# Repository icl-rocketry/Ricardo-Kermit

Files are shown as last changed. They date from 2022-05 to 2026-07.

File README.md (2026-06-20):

# Kermit
RAE board designed for data acquisition. All versions currently include power regulation for different types of analog sensors, as well as ADC and TC inputs.

# Supported Versions

## v3
v3 Kermit (nicknamed Kermit mini) includes:
  - [Ricardo Template](https://github.com/icl-rocketry/Ricardo-BoardTemplate) components.
  - 5V and 12V power outputs from an LDO.
  - 4 ADC channels with a theoretical maximum of 64kSPS from 1x ADS131M04 chip. All 4 channels can be configured for differential and single-ended inputs, 4-20mA input, voltage sensor input.
  - 2 Thermocouple chips (MAX31856) supporting every type of thermocouple.
  - SD Card for in-flight, and high rate, data acquisition.
  
## v2
v2 Kermit includes:
  - [Ricardo Template](https://github.com/icl-rocketry/Ricardo-BoardTemplate) components.
  - 5V and 10V power outputs from an LDO.
  - 12 ADC channels with a theoretical maximum of 32kSPS from 2x ADS131M06 chips. All 12 channels can be configured for differential and single-ended inputs, and 3.3V supply voltage sensors. 10 of the channels can be configured for 5v voltage-based sensors, and 2 of the channels can be configured for 4-20mA sensors (10V supply).
  - 4 Thermocouple chips (MAX31856) supporting every type of thermocouple.
  - SD Card for in-flight, and high rate, data acquisition.

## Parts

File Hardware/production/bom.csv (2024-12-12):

Designator | Footprint | Quantity | Value | LCSC Part #
12VLED1 | 0402 | 1 | RED_LED
3V3LED1 | 0402 | 1 | BLUE_LED
BOOTJUMPER1, ENJUMPER1 | PinHeader_1x02_P2.54mm_Vertical | 2 | Conn_01x02_Male
C1, C16, C20, C24, C26 | 0402 | 5 | 10uF
C10, C11, C27, C3, C49, C5, C54, C56, C57, C59, C6, C61, C62, C8 | 0402 | 14 | 0.1uF
C12 | 0603 | 1 | 2.2uF
C13, C14 | 0402 | 2 | 11pF
C15, C31, C33, C44, C45 | 0402 | 5 | 100nF
C17 | 0402 | 1 | 47nF
C18 | 0402 | 1 | 180pF
C19 | 0402 | 1 | 3.9nF
C2, C22, C4, C50, C51, C7 | 0402 | 6 | 1uF
C21, C38 | 0603 | 2 | 10uF
C23 | 0603 | 1 | 22uF
C25 | 0402 | 1 | 4.7uF
C28, C37 | 0402 | 2 | 1uF | CL05X105KA5NQNC
C29, C30, C41, C43 | 0805 | 4 | 22uF
C32, C42 | 0402 | 2 | 2.2uF | GRM155R61E225ME15D
C34 | 1206 | 1 | 47uF
C35 | 0402 | 1 | 10uF | CL05A106MP8NUB8
C36, C47 | 0402 | 2 | 100nF | C1005X5R1E104KT000E
C39 | 0402 | 1 | 120pF
C40 | 0402 | 1 | 2.2nF
C46 | 0603 | 1 | 10uF | TMK107BBJ106MA-T
C48 | 1206 | 1 | 22uF
C52 | 0402 | 1 | 220nF
C53, C55, C58, C60 | 0402 | 4 | 0.01uF
C63, C64, C65, C66, C9 | 0402 | 5 | 10nF
CANRXLED1 | 0402 | 1 | CANRXLED
CANTXLED1 | 0402 | 1 | CANTXLED
D1 | SOT-23 | 1 | SM712_SOT23
D2 | SOT-143 | 1 | SP0503BAHT
D3 | SOT-23 | 1 | MMBZ6V2ALT1G | MMBZ6V2ALT1G
D6 | RCLAMP3346PQTNT | 1 | RCLAMP3346PQTNT
H1, H2, H3, H4 | MountingHole_3.2mm_M3_DIN965_Pad | 4 | MountingHole_Pad
IC1, IC4 | IC_TPS61089RNRR | 2 | TPS61089RNRR | TPS61089RNRR
IC2, IC3 | SOT95P282X145-5N | 2 | AP2205-W5-7 | AP2205-W5-7
IC5 | QFN40P300X300X80-21N-D | 1 | ADS131M04IRUKR
J1 | Molex_Mini-Fit_Jr_5566-06A_2x03_P4.20mm_Vertical | 1 | RBUS
J2 | USB_C_Receptacle_Palconn_UTC16-G | 1 | USB_C_Receptacle_USB2.0
J4, J5, J6, J7 | Molex_Nano-Fit_105313-xx04_1x04_P2.50mm_Horizontal | 4 | 1053131104
J8 | PinSocket_2x05_P2.54mm_Vertical | 1 | GPIO Breakout
J9 | JAE_ST1W008S4TR2000 | 1 | ST1W008S4TR2000
JP1 | SolderJumper-2_P1.3mm_Open_RoundedPad1.0x1.5mm | 1 | TermJP
JP10, JP11, JP12, JP13, JP14, JP17, JP20, JP22, JP3, JP4, JP5, JP6 | SolderJumper-3_P1.3mm_Open_RoundedPad1.0x1.5mm_NumberLabels | 12 | SolderJumper_3_Open
JP15, JP16, JP18, JP19, JP2, JP21, JP7, JP8, JP9 | SmallerSolderJP | 9 | SolderJumper_2_Open
L1 | 0402 | 1 | 2.0nH
L2 | 0402 | 1 | 20nH
L3 | 0805 | 1 | 1uH
L4, L5 | IND_SRP6540-390M | 2 | SRR6038-5R0Y
Q1 | SOT-23 | 1 | PMOS | DMP3099L
R1, R14, R17, R20, R29, R3, R32, R38, R46, R61 | 0402 | 10 | 10K
R10, R9 | 0603 | 2 | 60
R11, R12, R13 | 0402 | 3 | 5.1k
R15, R36, R43, R49 | 0402 | 4 | 14k
R16 | 0402 | 1 | 56k
R18 | 0402 | 1 | 360k
R19, R27 | 0402 | 2 | 100k
R2, R4 | 0402 | 2 | 470
R21 | 0402 | 1 | 560k
R22, R28 | 0402 | 2 | 49.9k
R23 | 0402 | 1 | 150k
R24 | 0402 | 1 | 301k
R25 | 0402 | 1 | 18.7k
R26 | 0402 | 1 | 976k
R30 | 0402 | 1 | 475k
R31 | 0402 | 1 | 287k
R33, R40, R45, R48, R55, R56, R57, R58, R60, R62, R64 | 0402 | 11 | 1k
R34, R42, R47 | 0402 | 3 | 75k
R35 | 0402 | 1 | 75k | RT0402BRD0775KL
R37 | 0402 | 1 | 10k | ERA2ARB103X
R39 | 0402 | 1 | 14k | 0402WGF1402TCE
R41, R44, R59, R63 | 0402 | 4 | 49.9 | RT0402BRD0749R9L
R5 | 0402 | 1 | 7.87k
R50, R51, R52, R53 | 0402 | 4 | 100
R54 | 0402 | 1 | 54.9R
R6 | 0402 | 1 | 499R | AC0402FR-07499RL
R65 | 0402 | 1 | 432k
R7 | 0402 | 1 | 3k
R8 | 0603 | 1 | 0
TC1, TC2 | Molex_Nano-Fit_105313-xx02_1x02_P2.50mm_Horizontal | 2 | Thermocouple
TP1, TP2, TP3, TP4 | TestPoint_Pad_D1.0mm | 4 | TestPoint
TP5, TP6 | TestPoint_Pad_D1.5mm | 2 | TestPoint
TXLED1 | 0402 | 1 | GREEN_LED
U1 | QFN40P700X700X90-57N | 1 | ESP32-S3
U2 | SOIC-8_3.9x4.9mm_P1.27mm | 1 | SN65HVD230
U3 | SOTFL50P160X60-8N | 1 | LM66200DRLR
U4 | CONV_MAX77827AEFD+T | 1 | MAX77827AEFD+T
U5 | SOIC127P599X175-9N | 1 | SC4215
U6, U7 | TSSOP-14_4.4x5mm_P0.65mm | 2 | MAX31856
USBLED1 | 0402 | 1 | WHITE_LED
Y1 | Crystal_SMD_2016-4Pin_2.0x1.6mm | 1 | R940000171

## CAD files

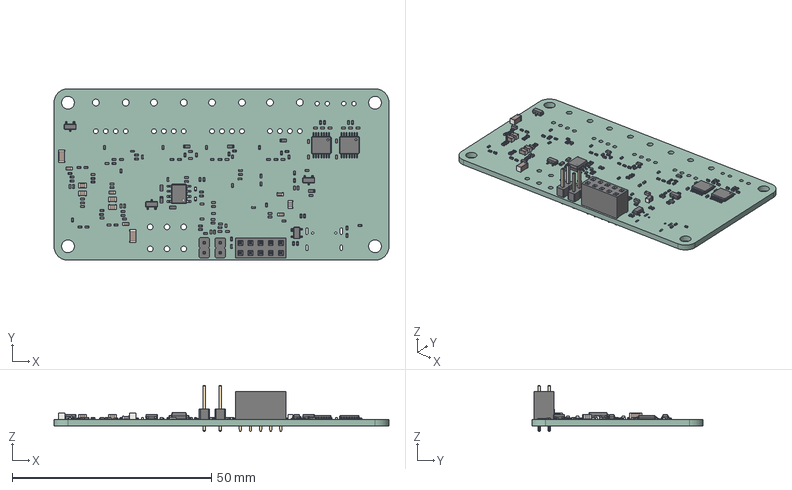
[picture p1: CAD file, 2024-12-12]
Hardware/Ricardo-Kermit-Mini.step
84.0 x 43.0 x 11.6 mm
R_0402_1005Metric x 66
C_0402_1005Metric x 55
R_0603_1608Metric x 7
C_0603_1608Metric x 5
PinSocket_2x05_P254mm_Vertical
TSSOP_14_44x5mm_P065mm x 2
L_0402_1005Metric x 2
C_1206_3216Metric x 2
PinHeader_1x02_P254mm_Vertical x 2
C_0805_2012Metric x 4
SOT_23 x 3
SOIC_8_39x49mm_P127mm
LED_0402_1005Metric x 2
SOT_143
L_0805_2012Metric
Ricardo-Kermit-Mini_PCB

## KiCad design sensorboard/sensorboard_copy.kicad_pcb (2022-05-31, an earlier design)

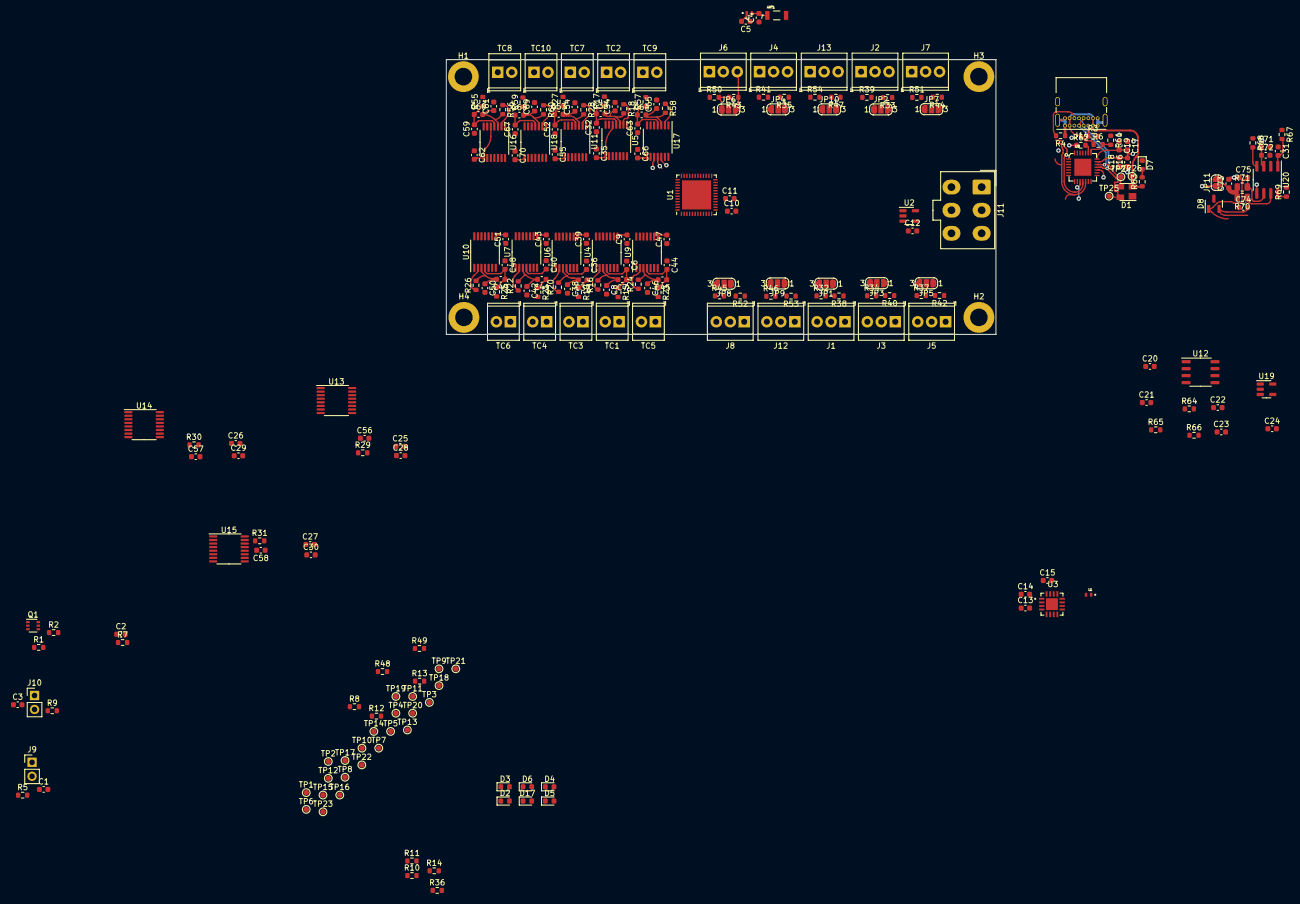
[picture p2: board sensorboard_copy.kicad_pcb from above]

Board: 4 copper layers, 100.0 x 50.0 mm, 244 parts (0 on the bottom side), 132 nets.

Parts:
ANT1: AMCA31-2R450G-S1F-T3; ANT_AMCA31-2R450G-S1F-T3
C1, C2, C3: 1nF; C_0603_1608Metric
C4: 1.2pF; C_0603_1608Metric
C5: 1.5pF; C_0603_1608Metric
C6, C8, C32, C34, C36, C38, C40, C42, C44, C46, C48, C50, C52, C54, C59, C61, C63, C65, C67, C69: 0.01uF; C_0603_1608Metric
C7, C9, C18, C19, C22, C33, C35, C37, C39, C41, C43, C45, C47, C49, C51, C53, C55, C56, C57, C58, C60, C62, C64, C66, C68, C70, C73: 0.1uF; C_0603_1608Metric
C10, C13, C20, C23, C25, C26, C27, C72: 10uF; C_0603_1608Metric
C11, C28, C29, C30, C71: 100nF; C_0603_1608Metric
C12, C16, C24: 4.7uF; C_0603_1608Metric
C14: 2.2uF; C_0603_1608Metric
C15: 100uF; C_0603_1608Metric
C17: 1.0uF; C_0603_1608Metric
C21: 1uF; C_0603_1608Metric
C31: 160pF; C_0603_1608Metric
C74: 220pF; C_0603_1608Metric
C75: 220 pF; C_0603_1608Metric
D1: SP0503BAHT; SOT-143
D2: RX_LED; LED_0603_1608Metric
D3: TX_LED; LED_0603_1608Metric
D4, D5: LED; LED_0603_1608Metric
D6: PWR_LED; LED_0603_1608Metric
D7, D17: USB_LED; LED_0603_1608Metric
D8: SM712_SOT23; SOT-23
H1, H2, H3, H4: MountingHole_Pad; MountingHole_3.2mm_M3_DIN965_Pad
J1, J2, J3, J4, J5, J6, J7, J8, J12, J13: Conn_01x03; TerminalBlock_TE_282834-3_1x03_P2.54mm_Horizontal
J9, J10: Conn_01x02_Male; PinHeader_1x02_P2.54mm_Vertical
J11: Conn_01x05_Male; Molex_Mini-Fit_Jr_5566-06A_2x03_P4.20mm_Vertical
J14: USB_C_Receptacle_USB2.0; USB_C_Receptacle_GCT_USB4085
JP1, JP2, JP3, JP4, JP5, JP6, JP7, JP8, JP9, JP10: SolderJumper_3_Open; SolderJumper-3_P1.3mm_Open_RoundedPad1.0x1.5mm_NumberLabels
JP11: SolderJumper_2_Open; SolderJumper-2_P1.3mm_Open_RoundedPad1.0x1.5mm
L1: 6.8uH; INDC1006X60N
L2: LQG15WZ1N8B02D; INDC1006X60N
Q1: MMDT2222A; SOT-363_SC-70-6
R1, R2, R7, R8: 10K; R_0603_1608Metric
R3, R4: 5.1k; R_0603_1608Metric
R5, R9, R10, R11, R12, R13, R14, R36, R63: 470; R_0603_1608Metric
R6: 24k; R_0603_1608Metric
R15, R16, R17, R18, R19, R20, R21, R22, R23, R24, R25, R26, R27, R28, R55, R56, R57, R58, R59, R60: 100; R_0603_1608Metric
R29, R30, R31, R48, R49: 1k; R_0603_1608Metric
R32, R33, R34, R35, R37, R43, R44, R45, R46, R47: 22k; R_0603_1608Metric
R38, R39, R40, R41, R42, R50, R51, R52, R53, R54: 43k; R_0603_1608Metric
R61, R66: 47k; R_0603_1608Metric
R62: 4.7k; R_0603_1608Metric
R64: 100k; R_0603_1608Metric
R65: 147k; R_0603_1608Metric
R67, R68: 90; R_0603_1608Metric
R69: 10k; R_0603_1608Metric
R70, R71: 60; R_0805_2012Metric
TC1, TC2, TC3, TC4, TC5, TC6, TC7, TC8, TC9, TC10: Thermocouple; TerminalBlock_TE_282834-2_1x02_P2.54mm_Horizontal
TP1, TP2, TP3, TP4, TP5, TP6, TP7, TP8, TP9, TP10, TP11, TP12, TP13, TP14, TP15, TP16, TP17, TP18, TP19, TP20, TP21, TP22, TP23, TP24, TP25, TP26: TestPoint; TestPoint_Pad_D1.0mm
U1: ESP32-PICO-D4; QFN-48-1EP_7x7mm_P0.5mm_EP5.3x5.3mm
U2, U19: LTC4411; SOT-23-5
U3: TPS61092RSAR; QFN65P400X400X100-17N
U4, U5, U6, U7, U9, U10, U11, U16, U17, U18: MAX31856; TSSOP-14_4.4x5mm_P0.65mm
U8: CP2102-GMR-QFN28; QFN28G_0.5-5X5MM
U12: RT9025-25GSP; SOP-8_3.9x4.9mm_P1.27mm
U13, U14, U15: ADS1219; TSSOP-16_4.4x5mm_P0.65mm
U20: SN65HVD230; SOIC-8_3.9x4.9mm_P1.27mm

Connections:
+3V3: C9.2, C10.1, C11.1, C12.1, C16.2, C17.2, C18.2, C19.2, C24.1, C25.1, C26.1, C27.1, C28.1, C29.1, C30.1, C35.2, C39.2, C43.2, C47.2, C51.2, C55.2, C56.2, C57.2, C58.2, C62.2, C66.2, C70.2, C71.1, C72.1, L1.1, R7.1, R8.1, R10.1, R11.1, R13.1, R14.2, R29.2, R30.2, R31.2, R48.2, R49.1, R62.1, U1.1 (VDDA), U1.3 (VDDA3P3), U1.4 (VDDA3P3), U1.19 (VDD3P3_RTC), U1.37 (VDD3P3_CPU), U1.43 (VDDA), U1.46 (VDDA), U2.5 (OUT), U3.8 (VBAT), U3.9 (LBI), U3.10 (SYNC), U3.11 (EN), U4.5 (AVDD), U4.8 (DVDD), U5.5 (AVDD), U5.8 (DVDD), U6.5 (AVDD), U6.8 (DVDD), U7.5 (AVDD), U7.8 (DVDD), U8.6 (VDD), U8.7 (REGIN), U9.5 (AVDD), U9.8 (DVDD), U10.5 (AVDD), U10.8 (DVDD), U11.5 (AVDD), U11.8 (DVDD), U13.3 (~RESET), U13.9 (REFP), U13.12 (AVDD), U13.13 (DVDD), U14.2 (A1), U14.3 (~RESET), U14.9 (REFP), U14.12 (AVDD), U14.13 (DVDD), U15.1 (A0), U15.2 (A1), U15.3 (~RESET), U15.9 (REFP), U15.12 (AVDD), U15.13 (DVDD), U16.5 (AVDD), U16.8 (DVDD), U17.5 (AVDD), U17.8 (DVDD), U18.5 (AVDD), U18.8 (DVDD), U19.5 (OUT), U20.3 (VCC)
+5V: C14.1, J1.2, J2.2, J3.2, J4.2, J5.2, J6.2, J7.2, J8.2, J12.2, J13.2, U3.1 (VOUT), U3.15 (VOUT), U3.16 (VOUT)
/BOOT: Q1.3 (C2), R8.2, R9.1, TP8.1, U1.23 (IO0)
/C55: TP11.1, U1.20 (IO13)
/CAN/Vref: JP11.1 (A), U20.5 (Vref)
/CAN_HIGH: C74.2, D8.2 (A2), J11.5, R70.1, U20.7 (CANH)
/CAN_LOW: C75.2, D8.1 (A1), J11.6, R71.2, U20.6 (CANL)
/CAN_RX: R68.1, TP23.1, U1.13 (IO33)
/CAN_TX: R67.1, TP22.1, U1.12 (IO32)
/CS0: TP21.1, U1.16 (IO27), U4.9 (~CS)
/CS1: TP20.1, U1.15 (IO26), U5.9 (~CS)
/CS2: TP19.1, U1.14 (IO25), U9.9 (~CS)
/CS3: TP13.1, U1.21 (IO15), U6.9 (~CS)
/CS4: TP12.1, U1.17 (IO14), U7.9 (~CS)
/CS6: TP10.1, U1.18 (IO12), U11.9 (~CS)
/CS7: TP9.1, U1.29 (SD3/IO10), U16.9 (~CS)
/CS8: TP2.1, U1.28 (SD2/IO9), U17.9 (~CS)
/CS9: TP1.1, U1.34 (IO5), U18.9 (~CS)
/DTR: Q1.4 (E2), R1.2, TP3.1, U8.28 (DTR)
/EN: C2.1, Q1.6 (C1), R5.1, R7.2, TP7.1, U1.9 (EN)
/LED: R12.1, U1.22 (IO2)
/LNA_IN: C5.2, L2.2, U1.2 (LNA_IN)
/MISO: TP15.1, U1.38 (IO19), U4.11 (SDO), U5.11 (SDO), U6.11 (SDO), U7.11 (SDO), U9.11 (SDO), U10.11 (SDO), U11.11 (SDO), U16.11 (SDO), U17.11 (SDO), U18.11 (SDO)
/MOSI: TP18.1, U1.36 (IO23), U4.12 (SDI), U5.12 (SDI), U6.12 (SDI), U7.12 (SDI), U9.12 (SDI), U10.12 (SDI), U11.12 (SDI), U16.12 (SDI), U17.12 (SDI), U18.12 (SDI)
/RTS: Q1.1 (E1), R2.2, TP6.1, U8.24 (RTS)
/RXD: D2.1 (K), TP5.1, U1.41 (U0TXD/IO1), U8.25 (RXD)
/SCL: R48.1, TP17.1, U1.39 (IO22), U13.16 (SCL), U14.16 (SCL), U15.16 (SCL)
/SCLK: TP14.1, U1.35 (IO18), U4.10 (SCK), U5.10 (SCK), U6.10 (SCK), U7.10 (SCK), U9.10 (SCK), U10.10 (SCK), U11.10 (SCK), U16.10 (SCK), U17.10 (SCK), U18.10 (SCK)
/SDA: R49.2, TP16.1, U1.42 (IO21), U13.15 (SDA), U14.15 (SDA), U15.15 (SDA)
/TXD: D3.1 (K), TP4.1, U1.40 (U0RXD/IO3), U8.26 (TXD)
/analogueI2C/AIN0: JP1.2 (C), U13.11 (AIN0)
/analogueI2C/AIN1: JP6.2 (C), U13.10 (AIN1)
/analogueI2C/AIN2: JP2.2 (C), U13.7 (AIN2)
/analogueI2C/AIN3: JP7.2 (C), U13.6 (AIN3)
/analogueI2C/AIN4: JP3.2 (C), U14.11 (AIN0)
/analogueI2C/AIN5: JP8.2 (C), U14.10 (AIN1)
/analogueI2C/AIN6: JP4.2 (C), U14.6 (AIN3)
/analogueI2C/AIN7: JP9.2 (C), U14.7 (AIN2)
/analogueI2C/AIN8: JP5.2 (C), U15.11 (AIN0)
/analogueI2C/AIN9: JP10.2 (C), U15.10 (AIN1)
/usb/Data+: D1.4 (K), J14.A6 (D+), J14.B6 (D+), TP25.1, U8.4 (D+)
/usb/Data-: D1.3 (K), J14.A7 (D-), J14.B7 (D-), TP24.1, U8.5 (D-)
GND: C1.2, C2.2, C3.2, C4.1, C5.1, C6.1, C8.2, C9.1, C10.2, C11.2, C12.2, C13.2, C14.2, C15.2, C16.1, C17.1, C18.1, C19.1, C20.1, C21.1, C23.1, C24.2, C25.2, C26.2, C27.2, C28.2, C29.2, C30.2, C31.1, C32.1, C34.2, C35.1, C36.1, C38.2, C39.1, C40.1, C42.2, C43.1, C44.1, C46.2, C47.1, C48.1, C50.2, C51.1, C52.1, C54.2, C55.1, C56.1, C57.1, C58.1, C59.1, C61.2, C62.1, C63.1, C65.2, C66.1, C67.1, C69.2, C70.1, C71.2, C72.2, C73.2, C74.1, C75.1, D1.1 (A), D4.1 (K), D5.1 (K), D6.1 (K), D7.1 (K), D8.3 (common), D17.1 (K), H1.1, H2.1, H3.1, H4.1, J1.1, J2.1, J3.1, J4.1, J5.1, J6.1, J7.1, J8.1, J9.2, J10.2, J11.1, J11.2, J12.1, J13.1, J14.A1 (GND), J14.A12 (GND), J14.B1 (GND), J14.B12 (GND), J14.S1 (SHIELD), R3.2, R4.1, R38.1, R39.1, R40.1, R41.1, R42.1, R50.1, R51.1, R52.1, R53.1, R54.1, R61.1, R64.2, R66.2, R69.2, U1.49 (GND), U2.2 (GND), U2.3 (CTL), U3.5 (PGND), U3.6 (PGND), U3.7 (PGND), U3.13 (GND), U3.17 (PGND), U4.1 (AGND), U4.14 (DGND), U5.1 (AGND), U5.14 (DGND), U6.1 (AGND), U6.14 (DGND), U7.1 (AGND), U7.14 (DGND), U8.3 (GND), U9.1 (AGND), U9.14 (DGND), U10.1 (AGND), U10.14 (DGND), U11.1 (AGND), U11.14 (DGND), U12.8 (GND), U13.1 (A0), U13.2 (A1), U13.4 (DGND), U13.5 (AGND), U13.8 (REFN), U14.1 (A0), U14.4 (DGND), U14.5 (AGND), U14.8 (REFN), U15.4 (DGND), U15.5 (AGND), U15.8 (REFN), U16.1 (AGND), U16.14 (DGND), U17.1 (AGND), U17.14 (DGND), U18.1 (AGND), U18.14 (DGND), U19.2 (GND), U19.3 (CTL), U20.2 (GND)
unnamed: ANT1.1, C4.2, L2.1
unnamed: C1.1, J9.1, R5.2
unnamed: C3.1, J10.1, R9.2
unnamed: C6.2, C7.1, R15.1, U4.4 (T+)
unnamed: C7.2, C8.1, R16.2, U4.3 (T-)
unnamed: C22.1, R65.2, R66.1, U12.7 (ADJ)
unnamed: C22.2, C23.2, R65.1, U12.6 (VOUT), U19.1 (IN)
unnamed: C31.2, R67.2, U20.1 (D)
unnamed: C32.2, C33.1, R17.1, U5.4 (T+)
unnamed: C33.2, C34.1, R18.2, U5.3 (T-)
unnamed: C36.2, C37.1, R19.1, U6.4 (T+)
unnamed: C37.2, C38.1, R20.2, U6.3 (T-)
unnamed: C40.2, C41.1, R21.1, U7.4 (T+)
unnamed: C41.2, C42.1, R22.2, U7.3 (T-)
unnamed: C44.2, C45.1, R23.1, U9.4 (T+)
unnamed: C45.2, C46.1, R24.2, U9.3 (T-)
unnamed: C48.2, C49.1, R25.1, U10.4 (T+)
unnamed: C49.2, C50.1, R26.2, U10.3 (T-)
unnamed: C52.2, C53.1, R27.1, U11.4 (T+)
unnamed: C53.2, C54.1, R28.2, U11.3 (T-)
unnamed: C59.2, C60.1, R55.1, U16.4 (T+)
unnamed: C60.2, C61.1, R56.2, U16.3 (T-)
unnamed: C63.2, C64.1, R57.1, U17.4 (T+)
unnamed: C64.2, C65.1, R58.2, U17.3 (T-)
unnamed: C67.2, C68.1, R59.1, U18.4 (T+)
unnamed: C68.2, C69.1, R60.2, U18.3 (T-)
unnamed: C73.1, JP11.2 (B), R70.2, R71.1
unnamed: D2.2 (A), R10.2
unnamed: D3.2 (A), R11.2
unnamed: D4.2 (A), R12.2
unnamed: D5.2 (A), R13.2
unnamed: D6.2 (A), R14.1
unnamed: D7.2 (A), R63.2
unnamed: D17.2 (A), R36.2
unnamed: J1.3, JP1.3 (B), R32.1
unnamed: J2.3, JP2.3 (B), R33.1
unnamed: J3.3, JP3.3 (B), R34.1
unnamed: J4.3, JP4.3 (B), R35.1
unnamed: J5.3, JP5.3 (B), R37.1
unnamed: J6.3, JP6.3 (B), R43.1
unnamed: J7.3, JP7.3 (B), R44.1
unnamed: J8.3, JP8.3 (B), R45.1
unnamed: J11.3, U2.1 (IN)
unnamed: J12.3, JP9.3 (B), R46.1
unnamed: J13.3, JP10.3 (B), R47.1
unnamed: J14.A5 (CC1), R3.1
unnamed: J14.B5 (CC2), R4.2
unnamed: JP1.1 (A), R32.2, R38.2
unnamed: JP2.1 (A), R33.2, R39.2
unnamed: JP3.1 (A), R34.2, R40.2
unnamed: JP4.1 (A), R35.2, R41.2
unnamed: JP5.1 (A), R37.2, R42.2
unnamed: JP6.1 (A), R43.2, R50.2
unnamed: JP7.1 (A), R44.2, R51.2
unnamed: JP8.1 (A), R45.2, R52.2
unnamed: JP9.1 (A), R46.2, R53.2
unnamed: JP10.1 (A), R47.2, R54.2
unnamed: L1.2, U3.3 (SW), U3.4 (SW)
unnamed: Q1.2 (B1), R1.1
unnamed: Q1.5 (B2), R2.1
unnamed: R6.2, R61.2, U8.8 (VBUS)
unnamed: R15.2, TC1.1 (+)
unnamed: R16.1, TC1.2 (-), U4.2 (BIAS)
unnamed: R17.2, TC2.1 (+)
unnamed: R18.1, TC2.2 (-), U5.2 (BIAS)
unnamed: R19.2, TC3.1 (+)
unnamed: R20.1, TC3.2 (-), U6.2 (BIAS)
unnamed: R21.2, TC4.1 (+)
unnamed: R22.1, TC4.2 (-), U7.2 (BIAS)
unnamed: R23.2, TC5.1 (+)
unnamed: R24.1, TC5.2 (-), U9.2 (BIAS)
unnamed: R25.2, TC6.1 (+)
unnamed: R26.1, TC6.2 (-), U10.2 (BIAS)
unnamed: R27.2, TC7.1 (+)
unnamed: R28.1, TC7.2 (-), U11.2 (BIAS)
unnamed: R29.1, U13.14 (~DRDY)
unnamed: R30.1, U14.14 (~DRDY)
unnamed: R31.1, U15.14 (~DRDY)
unnamed: R55.2, TC8.1 (+)
unnamed: R56.1, TC8.2 (-), U16.2 (BIAS)
unnamed: R57.2, TC9.1 (+)
unnamed: R58.1, TC9.2 (-), U17.2 (BIAS)
unnamed: R59.2, TC10.1 (+)
unnamed: R60.1, TC10.2 (-), U18.2 (BIAS)
unnamed: R62.2, U8.9 (~RST)
unnamed: R64.1, U12.1 (PGOOD)
unnamed: R68.2, U20.4 (R)
unnamed: R69.1, U20.8 (Rs)
VBUS: C20.2, C21.2, D1.2 (K), J14.A4 (VBUS), J14.A9 (VBUS), J14.B4 (VBUS), J14.B9 (VBUS), R6.1, R63.1, TP26.1, U12.2 (EN), U12.3 (VIN), U12.4 (VDD)

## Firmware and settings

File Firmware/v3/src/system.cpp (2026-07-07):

#include "system.h"

#include <memory>

#include <libriccore/riccoresystem.h>

#include <HardwareSerial.h>

#include "Config/systemflags_config.h"
#include "Config/commands_config.h"
#include "Config/pinmap_config.h"
#include "Config/general_config.h"

#include "Commands/commands.h"

#include "States/idle.h"

#include <cstdlib>
#include <cstdio>

#include "Loggers/TelemetryLogger/telemetrylogframe.h"


#ifdef CONFIG_IDF_TARGET_ESP32S3
static constexpr int VSPI_BUS_NUM = 0;
static constexpr int HSPI_BUS_NUM = 1;
#else
static constexpr int VSPI_BUS_NUM = VSPI;
static constexpr int HSPI_BUS_NUM = HSPI;
#endif

static constexpr uint16_t DISPLAY_WIDTH = 256;
static constexpr uint16_t DISPLAY_HEIGHT = 64;
static constexpr uint8_t DISPLAY_DRAW_COLOR_ON = 1;

static constexpr uint8_t ICLR_LOGO_WIDTH = 32;
static constexpr uint8_t ICLR_LOGO_HEIGHT = 32;

static const uint8_t ICLR_LOGO_XBM[] = {
    0x00, 0xf0, 0x0f, 0x00, 0x00, 0xde, 0x7f, 0x00, 0x80, 0xfd, 0xdf, 0x01, 0xc0, 0x67, 0x66, 0x03,
    0xe0, 0x39, 0x82, 0x05, 0xf0, 0x2c, 0x3c, 0x0f, 0xf8, 0x2e, 0xcc, 0x16, 0x7c, 0x16, 0xf0, 0x3d,
    0x5c, 0x23, 0x38, 0x38, 0x6e, 0x31, 0x1c, 0x56, 0xbe, 0x38, 0xc4, 0x77, 0x56, 0x0e, 0xf0, 0x6f,
    0x07, 0x30, 0xfc, 0xe0, 0xf7, 0x07, 0x04, 0xec, 0x17, 0x3e, 0x9c, 0xff, 0xff, 0x39, 0x70, 0xe0,
    0x05, 0x20, 0x04, 0xe0, 0x07, 0x3e, 0x9c, 0xff, 0xfd, 0x39, 0x7c, 0xe0, 0x37, 0x00, 0xe0, 0xe7,
    0x84, 0x3f, 0xf4, 0x6f, 0xee, 0x2f, 0xc0, 0x57, 0xea, 0x81, 0x08, 0x70, 0x5c, 0x08, 0xb0, 0x2b,
    0x3c, 0x0c, 0x70, 0x3c, 0x78, 0x47, 0xe2, 0x1e, 0xf0, 0x62, 0x46, 0x0f, 0xe0, 0xf9, 0x9f, 0x07,
    0xc0, 0xc7, 0xe3, 0x03, 0x80, 0xfb, 0xff, 0x01, 0x00, 0xfe, 0x7b, 0x00, 0x00, 0xf0, 0x0f, 0x00
};

System::System() : RicCoreSystem(Commands::command_map, Commands::defaultEnabledCommands, Serial),
                   canbus(systemstatus, PinMap::TxCan, PinMap::RxCan, 3),
                   SDSPI(VSPI_BUS_NUM),
                   SNSRSPI(HSPI_BUS_NUM),
                   TC0(SNSRSPI, PinMap::TC0_Cs),
                   TC1(SNSRSPI, PinMap::TC1_Cs, MAX31856::TCType::TT),
                   ADC0(SNSRSPI, PinMap::ADC0_Cs, PinMap::ADC_CLK),
                   display(U8G2_R0, PinMap::DISPLAY_SCLK, PinMap::DISPLAY_MOSI, PinMap::DISPLAY_CS, PinMap::DISPLAY_DC, PinMap::DISPLAY_RST),
                   CPT0(networkmanager, 0),
                   CPT1(networkmanager, 1),
                   Mass(networkmanager, 0),
                   Thrust(networkmanager, 1),
                //    FS0(networkmanager, PCNT_UNIT_0, PCNT_CHANNEL_0, PinMap::FS0, 0.001146158078),
                   primarysd(SDSPI,PinMap::SdCs_1,SD_SCK_MHZ(20),false,&systemstatus){};

void System::systemSetup()
{

    Serial.setRxBufferSize(GeneralConfig::SerialRxSize);
    Serial.begin(GeneralConfig::SerialBaud);
    setupDisplay();
  

    // initialize statemachine with idle state
    statemachine.initalize(std::make_unique<Idle>(systemstatus, commandhandler));

    canbus.setup();
    networkmanager.setNodeType(NODETYPE::HUB);
    networkmanager.setNoRouteAction(NOROUTE_ACTION::BROADCAST, {1, 3});
    networkmanager.addInterface(&canbus);

    // any other setup goes here

    pinMode(PinMap::SdCs_1, OUTPUT);
    pinMode(PinMap::ADC0_Cs, OUTPUT);
    pinMode(PinMap::TC0_Cs, OUTPUT);
    pinMode(PinMap::TC1_Cs, OUTPUT);
    pinMode(PinMap::SD_EN, OUTPUT);

    digitalWrite(PinMap::SdCs_1, HIGH);
    digitalWrite(PinMap::ADC0_Cs, HIGH);
    digitalWrite(PinMap::TC0_Cs, HIGH);
    digitalWrite(PinMap::TC1_Cs, HIGH);
    digitalWrite(PinMap::SD_EN, LOW);

    setupSPI();

    // Thermocouples:
    TC0.setup();
    TC1.setup();
    // ADCs:
    ADC0.setup();
    // Turbine Flow Sensor:
    // FS0.setup();

    ADC0.setOSR(ADS131M04::OSROPT::OSR8192);
    ADC0.setGain(0,ADS131M04::GAIN::GAIN1);
    ADC0.setGain(1,ADS131M04::GAIN::GAIN1);
    ADC0.setGain(2,ADS131M04::GAIN::GAIN1);
    ADC0.setGain(3,ADS131M04::GAIN::GAIN1);
    // ADC0.setGain(5, ADS131M06::GAIN::GAIN64);
    // ADC0.setGain(5, ADS131M06::GAIN::GAIN64);

    serviceSetup();

    remoteSensorSetup();

    primarysd.setup();

    initializeLoggers();
};

void System::systemUpdate()
{
    deviceUpdate();
    
    updateDisplay();

    remoteSensorUpdate();

    logReadings();
    // Serial.println((int)primarysd.getState());

    if((primarysd.getError() > 0) && !systemstatus.flagSet(SYSTEM_FLAG::ERROR_SD)){
        systemstatus.newFlag(SYSTEM_FLAG::ERROR_SD, "SD Card Failed with error: " + std::to_string(primarysd.getError()));
    };
};

void System::serviceSetup()
{
    networkmanager.registerService(10, CPT0.getThisNetworkCallback());
    networkmanager.registerService(11, CPT1.getThisNetworkCallback());
    networkmanager.registerService(12, Thrust.getThisNetworkCallback());
    networkmanager.registerService(13, Mass.getThisNetworkCallback());
}

void System::initializeLoggers()
{
    // check if sd card is mounted
    if (primarysd.getState() != StoreBase::STATE::NOMINAL)
    {
        loggerhandler.retrieve_logger<RicCoreLoggingConfig::LOGGERS::SYS>().initialize(nullptr, networkmanager);

        return;
    }

    // open log files
    // get unique directory for logs
    std::string log_directory_path = primarysd.generateUniquePath(log_path, "");
    // make new directory
    primarysd.mkdir(log_directory_path);

    std::unique_ptr<WrappedFile> syslogfile = primarysd.open(log_directory_path + "/syslog.txt", static_cast<FILE_MODE>(O_WRITE | O_CREAT | O_AT_END));
    std::unique_ptr<WrappedFile> telemetrylogfile = primarysd.open(log_directory_path + "/telemetrylog.csv", static_cast<FILE_MODE>(O_WRITE | O_CREAT | O_AT_END),100);

    // intialize sys logger
    loggerhandler.retrieve_logger<RicCoreLoggingConfig::LOGGERS::SYS>().initialize(std::move(syslogfile), networkmanager);

    // initialize telemetry logger
    std::string file_header = "ch0sens,ch1sens,ch2sens,ch3sens,tc0(C),tc1(C),time(ms)";
    loggerhandler.retrieve_logger<RicCoreLoggingConfig::LOGGERS::TELEMETRY>().initialize(std::move(telemetrylogfile),file_header,[](std::string_view msg){RicCoreLogging::log<RicCoreLoggingConfig::LOGGERS::SYS>(msg);});
}

void System::deviceUpdate()
{

    ADC0.update();

    TC0.update();
    TC1.update();

    // FS0.update();
}

void System::remoteSensorUpdate()
{

    CPT0.update(ADC0.getOutput(0));
    CPT1.update(ADC0.getOutput(1));
    Thrust.update(ADC0.getOutput(2));
    Mass.update(ADC0.getOutput(3));
}
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

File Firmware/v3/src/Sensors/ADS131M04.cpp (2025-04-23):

/* This is a library for the ADS131M04 6-channel ADC
   
   Product information:
   https://www.ti.com/product/ADS131M04/part-details/ADS131M04IPBSR

   Datasheet: 
   https://www.ti.com/lit/ds/symlink/ADS131M04.pdf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

   This library was made for Imperial College London Rocketry
   Created by Aleksandr Kent
   
   Based on ADS131M04-Lib by Daniele Valentino Bella & Iris Clercq-Roques:
   https://github.com/icl-rocketry/ADS131M04-Lib
*/

#include <Arduino.h>
#include <SPI.h>
#include <esp32-hal-ledc.h>
#include "ADS131M04.h"
#include <libriccore/riccorelogging.h>

ADS131M04::ADS131M04(SPIClass &_spi, uint8_t _csPin, uint8_t _clkoutPin, uint8_t _clockCh):
spi(_spi),
_spisettings(SCLK_SPD, MSBFIRST, SPI_MODE1),
csPin(_csPin),
clkoutPin(_clkoutPin),
clockCh(_clockCh),
clockEnabled(true),
initialised(false)
{}

ADS131M04::ADS131M04(SPIClass &_spi, uint8_t _csPin):
spi(_spi),
_spisettings(SCLK_SPD, MSBFIRST, SPI_MODE1),
csPin(_csPin),
clockEnabled(false),
initialised(false)
{}
//-----------------------------------------------------------------------------------------------------------------------------------------------
void ADS131M04::setup() {
  pinMode(csPin, OUTPUT);//set the pinmode of csPin to output data
  digitalWrite(csPin, HIGH);//set the csPin to output high (active low)
  reset();
  /* Set CLKOUT on the ESP32. used for generation of the ADC clock signal using ledc.
    Define the individual clock channel to generate the signal and the clock frequency to
    generate it at.
    AttachPin takes the GPIO pin which will be attached to the channel specified.
    
  */

  if (clockEnabled == true)
  {
    ledcAttach(clkoutPin, CLKIN_SPD, 2);
    ledcWrite(clkoutPin, 2);
  }

  setOSR(OSROPT::OSR16256);
  
  initialised=true;
}
//------------------------------------------------------------------------------------------------------------------------------------------------
void ADS131M04::update(){

  rawChannels(outputArray);

}

void ADS131M04::rawChannels(std::array<int32_t,4>& outputArray) {
  /* Writes data from the channels specified in channelArr, to outputArr,
     in the correct order.

     channelArr should have values from 0-5 (specifying the 6 ADC channels), and channelArrLen should be the
     length of that array, starting from 1. (length = 4 if 0-3 channels are used)
     function is void as pointers are used to modify the arrays which are passed into the function.
  */
    spiCommFrame(responseArray); 

    // Save the decoded data for each of the channels
    for (int8_t i = 0; i < outputArray.size(); i++) {
        outputArray[i] = twoCompDeco(responseArray[i+1]);
    }

}

bool ADS131M04::writeReg(uint8_t reg, uint16_t data) {
  uint8_t commandPref = 0x06;//0000 0110

  // Make command word using syntax found in data sheet
  uint16_t commandWord = (commandPref<<12) + (reg<<7);

  digitalWrite(csPin, LOW);
  spi.beginTransaction(_spisettings);
  
  // sends command word and data to be written in the register location along the SPI lines. return data is discarded (not assigned to anything)
  spiTransferWord(commandWord);

  /*Use transferWord() function instead of spiCommFrame() since the data needs to be sent directly
  after the command, instead of the 6 empty words being sent after the command in spiCommFrame()*/
  spiTransferWord(data);

  // Send 4 empty words
  for (uint8_t i=0; i<4; i++) {
    spiTransferWord(); //sends 2bytes of zeros by default. completes the 8 word frame
  }

  spi.endTransaction();
  digitalWrite(csPin, HIGH); //active low due to CPHA as mentioned before, therefore deactivate here.

  // Get response in order to determine whether the writing was successfull:
  spiCommFrame(responseArray); // Copy SPI data from all channels into the responseArr[]

  // Determining whether the register was successfully written to or not:
  //response format: 010a aaaa ammm mmmm
  if ( ( (0x04<<12) + (reg<<7) ) == (responseArray[0] >> 16)) { //check against the 16 bit response
    return true;
  } else {
    return false;
  }
}

uint16_t ADS131M04::readReg(uint8_t reg){
  //reg: aaaa aaaa 8 bits, however, no register address requires more than 6 bits other than the RESERVED address (requires 7 bits)
  uint8_t commandPref = 0x0A;//10 = 0000 1010
  //1010 0000 0000 0000
  // Make command word using syntax found in data sheet: 101a aaaa annn nnnn
  uint16_t commandWord = (commandPref << 12) + (reg << 7);

  //Define response array:

  // Use first frame to send command
  spiCommFrame(responseArray, commandWord);

  // Read response: response occurs on the output frame following the command, rather than at the same time the command is sent.
  spiCommFrame(responseArray);//xxxx test if this actuall gets the register data (might just output
  //the channel data, which is not what we want here)
  return (responseArray[0] >> 16); //return the 2bytes of actual data in the first index of the array.

}
//---------------------------------------------------------------------------------------------------------------------------------------------
bool ADS131M04::clkConfig(){
  /*Writes to the clock register and sets crystal oscillator to disable and enable */

  uint16_t data = 0b0011111111001110;
  return(writeReg(CLOCK, data));
}
//-----------------------------------------------------------------------------------------------
bool ADS131M04::reset(){
  uint16_t commandWord = 0x11;

  uint16_t commandResponse = (0xFF <<8) + 0x22; //expected response to be checked against

  spiCommFrame(responseArray, commandWord);
  spiCommFrame(responseArray);

  // check if command was acknowledged:
  if((responseArray[0] >> 16) == commandResponse){ //reponseArr is 32bit MSB aligned, therefore shift 16 and get rid of LSB zeroes.
    return true;
  }else{
    return false;
  }
}

bool ADS131M04::standby(void){
  /*Enter standby mode for the ADC
    output true if successfull
  */
  uint16_t commandWord = 0x20;

  spiCommFrame(responseArray, commandWord);
  spiCommFrame(responseArray);

  // check if command was acknowledged:
  if((responseArray[0] >> 16) == commandWord){//response word is the same as the commandword
    return true;
  }else{
    return false;
  }
}
bool ADS131M04::wakeup(void){
  /*Wakeup from the standby mode
    Output true if successfull*/
  uint16_t commandWord = 0x33; // 0000 0000 0011 0011


  spiCommFrame(responseArray, commandWord);
  spiCommFrame(responseArray);

  // check if command was acknowledged:
  if((responseArray[0] >> 16) == commandWord){//response word is the same as the commandword
    return true;
  }else{
    return false;
  }
}
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

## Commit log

2021-11-08 Initial sensor board schematic
    Laid out initial sensor board schematic for up to 12 ch inputs with 250Hz max sampling rate (at maximum oversampling rate of 16384) on continuous sampling mode
    [IMU.sch, Mainboard.kicad_pcb, Mainboard.sch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]
2021-11-09 Voltage divider setup
    Voltage divider setup, removed unused components, CAN RX/TX empty for now (waiting for kiran)
    [Mainboard.sch, analogue.sch, power.sch]
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2021-11-13 I2C ADC conversion+MCP31856 x10
    As above xD
    just need to do the pcb layout
    [Mainboard.sch, analogue.sch, analogueI2C.sch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]
2021-12-04 Small edits
    removed a floating extra antenna
    [Mainboard.sch]
2022-03-29 added 5v boost to schematic, should be ready for layout
    [IMU.sch, Mainboard.kicad_pcb, Mainboard.kicad_sch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]
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2022-04-04 Stackup + capacitor fps
    [CAN.kicad_sch, analogueI2C.kicad_sch, sensorboard.kicad_pcb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]
2022-04-05 usb-uart structure done
    Original FPs were used, copies from usb were deleted, however the structure was kept the same
    [sensorboard.kicad_pcb]
2022-04-13 CAN structure done
    Main structure copied across from actuator board, fps from sensor board used
    [sensorboard.kicad_pcb]
2022-04-15 antenna and thermocouple prelim
    Preliminary layout for thermocouples and antenna structure done
    [sensorboard.kicad_pcb, sensorboard.kicad_sch, thermocouple.kicad_sch]
2022-04-16 Changed diode fps from castellated
    [sensorboard.kicad_pcb, sensorboard.kicad_sch, thermocouple.kicad_sch]
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2022-05-31 Update thermocouple connection
    changed schematic (c55 --> cs5) and positions. Copies made
    [sensorboard_copy.kicad_pcb, sensorboard_copy.kicad_sch, thermocouple.kicad_sch]
2022-06-03 thermocouple tps and connection update
    [sensorboard.kicad_pcb]
2022-06-04 I2C connections
    connected analogue i2c components
    [sensorboard.kicad_pcb]
2022-06-07 Integrated in USB and CAN
    CAN_TX and CAN_RX are moved
    [sensorboard.kicad_sch, thermocouple.kicad_sch]
2022-06-07 3.3V connections and I2C capacitors
    [sensorboard.kicad_pcb]
2022-06-11 moved the U14 component and added component
    [sensorboard.kicad_pcb, sensorboard.kicad_sch]
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2022-06-18 connectors and changed capacitor values
    capacitors for the connectors to 0.1uf
    [sensorboard.kicad_pcb, sensorboard.kicad_sch]
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2022-06-27 Initial GND fill and fixed CAN_HIGH
    [sensorboard.kicad_pcb]
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2022-07-03 Swapped the antenna for the coaxial connector
    [analogueI2C.kicad_sch, sensorboard.kicad_pcb, sensorboard.kicad_sch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]
2022-07-13 USB moved, changed layer ln.2 to 3.3V
    Fixed the GND fill
    [sensorboard.kicad_pcb]
2022-07-13 Change 3.3V, added curved edges
    changed the copy, added keepout for UFL connector
    [analogueI2C.kicad_sch, sensorboard - Copy.kicad_pcb, sensorboard - Copy.kicad_sch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]
2022-07-13 changed BOOT pin, auto reset caps
    moved references about
    [CAN.kicad_sch, sensorboard.kicad_pcb, sensorboard.kicad_sch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]
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2022-07-24 fixed clearance issues
    clearance set to 0.21mm
2022-07-26 boost converter fixed
    rearrangement of coaxial connector line and gnd stitching
    [sensorboard.kicad_sch, thermocouple.kicad_sch]
2022-07-27 Changed pins for CAN lines and removed LED
    need to rearrange LNA_IN line for less interference
    [sensorboard.kicad_sch, thermocouple.kicad_sch]
2022-07-27 added silkscreens and fixed LNA_IN line
    fixed labels for TPs and LEDs
    [analogueI2C.kicad_sch, sensorboard.kicad_sch, thermocouple.kicad_sch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]
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2022-07-30 fixed CS lines
    before cleanup
    [sensorboard - Copy.kicad_sch]
2022-08-04 Connected LDO and CP2102 EPs to GND, expanded U.FL keepout
    [sensorboard.kicad_sch, usb.kicad_sch]
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2022-09-01 Added pin defs, shamelessly stolen .ini and partition files
    also moved ADS class and added the code I used to test 1 ADC channel
    [sensrpart.csv]
2022-09-09 Copied ric-gateway,added getOffset and readAdjusted methods to ADS class
    [ricpart.csv]
2022-09-12 fixed canbus
2022-09-18 offset calibration code fixed, found offsets for 1 of the sensor boards
    [ADS1219.cpp, main.cpp]
2022-09-19 fixed the ADS class
    [ADS1219.cpp, main.cpp]
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2022-10-14 fixed ptaps and thermistor, load cell needs calibration
    [ADS1219.cpp, main.cpp]
2022-10-21 EUROC fixes (I don't remember what I changed)
    [ADS1219.cpp, main.cpp]
2022-11-05 Add pickle SD card + delete copies
    need to finish IO
    [microSDcard.kicad_sch, sensorboard - Copy.kicad_sch, sensorboard.kicad_sch]
2022-11-05 SD hierarchical labels
    need to connect to new GPIO for esp32-s3
    [microSDcard.kicad_sch, sensorboard.kicad_sch]
2022-11-08 integrated new ESP32-s3
    Need to remove excess thermocouples
    [CAN.kicad_sch, sensorboard - Copy.kicad_sch, usb-uart.kicad_sch]
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2022-12-06 values for ADC caps and connector circuits
    ADC cap values based on assumptions
    [analogueI2C.kicad_sch, sensorboard.kicad_sch]
2022-12-06 fixed hierarchical labels and added ref values
    [CAN.kicad_sch, analogueI2C.kicad_sch, microSDcard.kicad_sch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]
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2022-12-13 update
    still need to fix 10v rail
    [Boosts.kicad_sch, CDC.kicad_sch, analogueI2C.kicad_sch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]
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2023-01-24 added template changes
    Moved power to seperate file
    [CAN.kicad_sch, power.kicad_sch, sensorboard.kicad_sch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]
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2023-03-11 changed pins layout for esp
    update for ADC traces
    [analogueI2C.kicad_sch, power.kicad_sch, sensorboard.kicad_pcb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]
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2023-03-18 Powerlines and LDO layout
    updated fp for usb
    [Boosts.kicad_sch, sensorboard.kicad_pcb, usb-uart.kicad_sch]
2023-03-18 fix usb lines
    [sensorboard.kicad_pcb]
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2023-05-16 slight changes to TC driver, will probably revert some of them
    [MAX31856.cpp]
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2023-05-23 changes to schematic
    added in components for the layout
    [Boosts.kicad_sch, sensorboard.kicad_sch]
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2023-06-03 fixed the CAN
    [CAN.kicad_sch, sensorboard.kicad_sch]
2023-06-04 ADS line fix and schematic
    [analogueI2C.kicad_sch, sensorboard.kicad_sch]
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2023-06-10 differential running and fixed ADS schematic
    [analogueI2C.kicad_sch]
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2023-06-10 JTAG tps fixed and teardrops
    [sensorboard.kicad_sch]
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2023-07-06 fixed spi lines
2023-07-07 rerouted USB D traces, redid ADSCLK and source termination, some...
    ... other small things too.
    [analogueI2C.kicad_sch, sensorboard.kicad_sch]
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2023-07-08 rounding traces, ESD changes, boost footprints, removed drc exclusions
    [Boosts.kicad_sch, CAN.kicad_sch, microSDcard.kicad_sch]
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2023-08-14 added ADS drivers (incomplete)
    starting implementation and some documentation. need to fix stuff
    [ADS131M06.h]
2023-08-14 Pinmap and ADC implementation update
    need to sort out ledc
    [Boosts.kicad_sch, sensorboard.kicad_sch]
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2023-08-19 Fixed submodules
    [app3M_fat9M_16MB.csv, bare_minimum_2MB.csv, default.csv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]
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2023-08-24 updated ADS drivers (requires testing)
    twocompdecomp requires fixing. testing required. pushing changes before stuff is messed up
    [ADS131M06.h, commands.cpp, system.cpp]
2023-08-26 changed c style arrays to vects and fixed compile errors
    [ADS131M06.h]
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2023-09-03 Fixed ADC shifted channels issue
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2023-09-18 tryna fix the crashing
    [ADS131M06.h]
2023-09-25 fixed some bugs. updated libriccore to latest, redirected syslogger to librricore implmenetation, decreased log delta
    [system.cpp]
2023-09-27 updated file opening to correct oflags
    [system.cpp]
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2024-01-23 Revert "Merge remote-tracking branch 'refs/remotes/origin/main'"
    This reverts commit c9a99cb72454eddb78504ad976151236a8d13e5c, reversing
    changes made to 3cdb2e540a9938f01cf78ecb1078cc5742e66bb5.
    [AMCA31-2R450G-S1F-T3.step, Boosts.kicad_sch, CAN.kicad_sch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]
2024-02-08 tc update delta, fixed flow sensor k
    [ADS131M06.h, MAX31856.cpp, system.cpp]
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2024-03-17 .ini change for SD card fixes
    [MAX31856.cpp, commands.cpp]
2024-03-22 Added sd card error checking in systemstatus
    [system.cpp]
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2024-07-22 added diodes on gpio breakout and sensor supply
    [Ricardo-Kermit-Mini.kicad_pcb, Ricardo-Kermit-Mini.kicad_sch, boosts_sch.kicad_sch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]
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2024-07-28 changed ldo output to 12v, kiran review done
    [Ricardo-Kermit-Mini.kicad_pcb, boosts_sch.kicad_sch]
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2024-08-15 p mosfet pinout fix
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2024-12-12 Moved kermit mini firmware to its own firmware folder
    [ricpart.csv]
2024-12-12 Moved v2(board iteration) firmware to its own folder
    [ricpart.csv]
2024-12-12 USB and power schematics died in the merge
    [USB_sch.kicad_sch, microSD_sch.kicad_sch, power.kicad_sch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]
2025-01-08 Esp-idf doesn't like brackets in folder name + more merge fixes
    [ricpart.csv]
2025-01-08 v2 firmware fixed too.
    [ADS131M06.h, commands.cpp]
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2025-01-13 Copied over partition and sdk settings from template
    [ricparts3.csv]
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2025-04-23 reset on initialising ADS131M04 and fast millis in MAX31856 loop
    [ADS131M04.cpp, MAX31856.cpp]
2025-04-23 Replaced micros call with esp timer
    [system.cpp]
2025-05-16 Rolled back arduino due to compile errors
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2026-07-07 Replace esp_timer_get_time() with millis() and switch time-related variables to milliseconds.
    [system.cpp]
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
